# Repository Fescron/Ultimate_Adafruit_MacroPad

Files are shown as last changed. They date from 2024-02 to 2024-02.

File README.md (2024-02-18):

# Ultimate_Adafruit_MacroPad







This repository contains **necessary components** and **fabrication instructions** for my **Ultimate Adafruit Macropad**, as well as the **code and macro-definitions** I run on it. **Configuration and usage instructions** are also listed here.

I've basically added two [NeoKey 1x4 boards](https://www.adafruit.com/product/4980) next to the [Adafruit Macropad](https://www.adafruit.com/product/5128) to simplify macro-layer-switching. I've found that pressing a button to change a macro-layer on the Macropad is much faster than rotating the encoder, certainly if there are (currently) more than 25 layers defined. The encoder is repurposed to change macro-selection-layers on the NeoKey buttons. To have an additional (apart from the button color) indication of what Macropad layer can be activated using a specific NeoKey button, I've also added a [1.3" 128x64 OLED display](https://www.adafruit.com/product/938) above the NeyKey boards.

I've subsequently (heavily) modified the original [Macropad Hotkeys code](https://learn.adafruit.com/macropad-hotkeys?view=all) to work with these additional buttons and display, as wel as added functionality to use other keyboard layouts (using code from [this](https://github.com/Neradoc/Circuitpython_Keyboard_Layouts) repository) and to dim the displays and button-LEDs after some time (using code from [this](https://github.com/M-Eldin/Adafruit-MacroPad-RP2040-Sleep) repository). Since the default firmware on the Macropad doesn't support two displays I've also had to compile new CircuitPython firmware to flash to the Macropad.

Ultimate Adafruit Macropad

<br>

## 0 - Repository Structure

| Folder | Contents |
|---|---|
| [`CIRCUITPY`](CIRCUITPY/) | All files *as-is* on my Ultimate Adafruit Macropad. It contains libraries (`lib`), macros (`macros`), the main `code.py`-file, a quick reference to keycodes (`Keycodes.txt`) and a [VSCode](https://code.visualstudio.com/) workspace (`workspace.code-workspace`) to quickly open some files to I can edit them. |
| [`img`](img/) | Images displayed on this README. |
| [`pcb`](pcb/) | Two (custom) [KiCad](https://www.kicad.org/) PCBs to assemble the Ultimate Adafruit Macropad. |
| [`uf2`](uf2/) | A [CircuitPython](https://circuitpython.org/) firmware-file for the Adafruit Macropad with support for two screens. |

<br>

## 1 - Construction (Hardware)

### 1.1 - Materials

The **Ultimate Adafruit Macropad** is constructed using the materials from the tables below. Note that my version is *very fancy*, with very expensive (but amazing looking) windowed keycaps. These are certainly not required, and instead an [Adafruit MacroPad RP2040 Starter Kit](https://www.adafruit.com/product/5128) with included basic keycaps and switches can also be purchased.

Also note that the NeoKey 1x4 boards ship without switches and keycaps, they need to be purchased separately. In case the [Adafruit MacroPad RP2040 Starter Kit](https://www.adafruit.com/product/5128) is bought (instead of the [Adafruit MACROPAD RP2040 Bare Bones](https://www.adafruit.com/product/5100) board) individual switches and keycaps still need to be purchased for the NeoKey boards.

| Qty | Description | Link |
|---|---|---|
| 1 | Adafruit MACROPAD RP2040 Bare Bones | https://www.adafruit.com/product/5100 |
| 2 | Kailh Mechanical Key Switches - Tactile Brown - 10 pack | https://www.adafruit.com/product/4954 |
| 2 | NeoKey 1x4 QT I2C | https://www.adafruit.com/product/4980 |
| 20 | Black Windowed Lamp R4 Keycap for MX Compatible Switches | https://www.adafruit.com/product/5112 |
| 1 | STEMMA QT / Qwiic JST SH 4-Pin Cable - 50mm Long | https://www.adafruit.com/product/4399 |
| 1 | Monochrome 1.3" 128x64 OLED graphic display - STEMMA QT / Qwiic | https://www.adafruit.com/product/938 |
| 1 | Anodized Aluminum Machined Knob - Black - 20mm Diameter | https://www.adafruit.com/product/5527 |
| 1 | Adafruit MacroPad RP2040 Enclosure + Hardware Add-on Pack | https://www.adafruit.com/product/5103 |
| 1 | Baseboard PCB | (see [these](pcb/ultimate-adafruit-macropad-baseboard/gerber/) gerber-files) |
| 1 | Keyplate PCB | (see [these](pcb/ultimate-adafruit-macropad-keyplate/gerber/) gerber-files) |

Additionally some more generic items are necessary and/or can be useful.

| Description | Usage | Link(s) |
|---|---|---|
| Male (and female) 2.54mm/0.1" pinheaders | Mounting the NeoKey and OLED boards to the Baseboard PCB | https://www.adafruit.com/product/392 https://www.adafruit.com/product/598 |
| Black Nylon Machine Screw and Stand-off Set - M2.5 Thread | Mounting the NeoKey and OLED boards to the Baseboard PCB | https://www.adafruit.com/product/3299 |
| Black Nylon Machine Screw and Stand-off Set - M3 Thread | Mounting the Macropad to the Boaseboard PCB | https://www.adafruit.com/product/4685 |
| 2 pcs Laptop riser feet | Setting the board on an angle for easier usage | https://www.aliexpress.com/item/1005003557570061.html |
| 12x5mm 40 pcs round rubber pads | Making sure the board doesn't slide around | https://www.aliexpress.com/item/33030992785.html |
| Carrying case | Protecting the board during travel | https://www.aliexpress.com/item/1005001855670902.html |

<br>

### 1.2 - Assembly

As the last two entries in the first material-table already suggested, I've also designed two custom PCBs to facilitate a fairly easy assembly and final sturdy device. The [Baseboard PCB](pcb/ultimate-adafruit-macropad-baseboard/) is used to mount all boards to a single PCB, while also facilitating some interconnections between the components. Only a single Stemma QT / Qwiic cable (in an out-of-sight spot) is required, the rest of the connections are done by the Baseboard.

The second PCB, the [Keyplace PCB](pcb/ultimate-adafruit-macropad-keyplate/), is used to secure the eight mechanical switches to the two NeoKey boards. It basically has the same functionality as the keyplace-PCB does for the Adafruit Macropad (included in the [Adafruit MacroPad RP2040 Enclosure + Hardware Add-on Pack](https://www.adafruit.com/product/5103) or [Adafruit MacroPad RP2040 Starter Kit](https://www.adafruit.com/product/5128)).

#### The assembly-steps are the following

1. Solder male 2.54mm/0.1" pinheaders to the Baseboard (one with 01x08 pins for the OLED, two with 01x06 pins for the NeoKey boards).
2. Close solder-jumper `A0` of the left-most NeoKey 1x4 board to set its I2C address to `0x31`. The right-most NeoKey 1x4 board will keep its default address of `0x30`.
3. Solder female 01x06 2.54mm/0.1" headers to the NeoKey boards.
4. Solder a female 01x08 2.54mm/0.1" header to the OLED display. Also cut the mounting-holes on the bottom of this board so it can be mounted closer to the NeoKey boards.
5. Screw the Macropad to the Baseboard using M3 hardware.
6. Screw the NeoKey boards to the Baseboard using M2.5 hardware.
7. Connect the STEMMA QT / Qwiic cable from the Macropad to the top of the left-most NeoKey board.
8. Screw the OLED display to the Baseboard using M2.5 hardware.
9. Mount the mechanical keys to the Macropad. Make sure to not forget the keyplate in between the Macropad and the keys.
10. Mount the mechanical keys to the NeoKey boards. Make sure to not forget the (custom) keyplate in between the boards and the keys.
11. Mount the rotary encoder knob on the rotary encoder. Put the keycaps on the mechanical switches. Mount the riser feet to the bottom of the Baseboard.
12. (Optional, if the carrying case is used): Cut a foam-insert for the inside of the case to keep the Ultimate Adafruit Macropad from moving around.

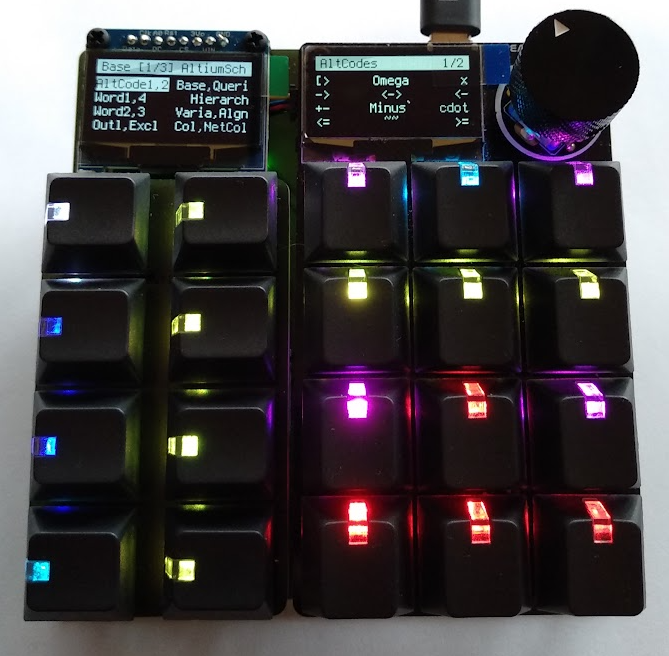
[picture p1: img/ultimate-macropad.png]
Ultimate Adafruit Macropad
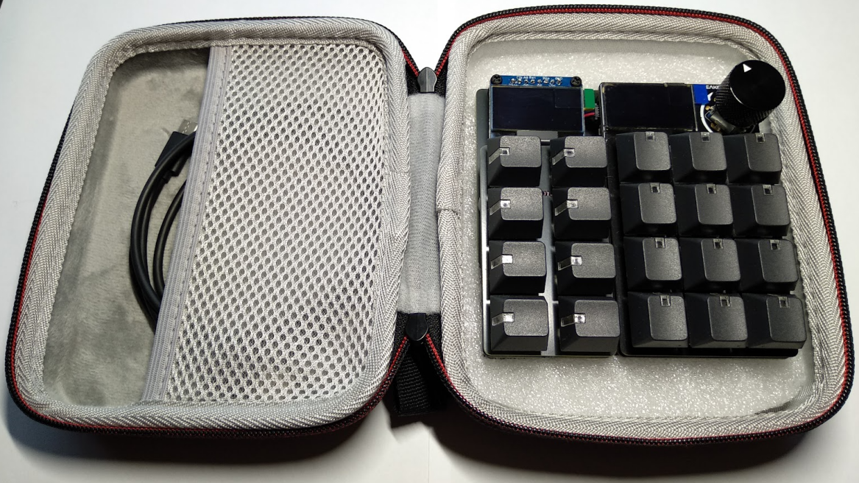
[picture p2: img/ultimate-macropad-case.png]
Ultimate Adafruit Macropad inside a case
|  |  |
|--|--|

<br>

## 2 - Firm/Software

### 2.1 - Firmware

As already mentioned, the default [CircuitPython](https://circuitpython.org/) firmware for the Adafruit Macropad doesn't support two screens. Fortunately it is possible to build `.uf2`-files yourself which do support this. The result of this is placed in the [`uf2`](uf2/) directory on this repository.

<details>

  <summary>For reference, the following (Linux/Ubuntu) steps/commands can be used to build the file yourself</summary>
  
  ```bash
  ## https://learn.adafruit.com/building-circuitpython/linux
  # Install additional software
  sudo apt install build-essential
  sudo add-apt-repository ppa:git-core/ppa
  sudo add-apt-repository ppa:pybricks/ppa
  # Download the appropriate ARM Cortex-M toolchain
  # (for CircuitpPython 8.x: 10-2020-q4-major https://developer.arm.com/downloads/-/gnu-rm)
  # Unpack it in a convenient directory
  mkdir ~/bin
  cd ~/bin
  tar xvf gcc-arm-none-eabi-10-2020-q4-major-x86_64-linux.tar.bz2
  # Add a link to the toolchain executables in PATH
  sudo nano ~/.profile
    export PATH=/home/$USER/bin/gcc-arm-none-eabi-10-2020-q4-major/bin:$PATH
  # Logout and log back in
  # Check if the link is correctly configured
  which arm-none-eabi-gcc

  ## https://learn.adafruit.com/building-circuitpython/build-circuitpython
  # Clone the repository
  git clone https://github.com/adafruit/circuitpython.git
  cd circuitpython
  # Install needed Python packages from pypi.org.
  pip3 install --upgrade -r requirements-dev.txt
  pip3 install --upgrade -r requirements-doc.txt
  # Checkout the latest stable branch (as per https://circuitpython.org/board/adafruit_macropad_rp2040/)
  git checkout 8.2.8
  # Fetch submodules (for a specific ports/... device)
  cd ports/raspberrypi
  make fetch-port-submodules
  # Build mpy-cross
  cd ../..
  make -C mpy-cross

  ## https://todbot.com/blog/2022/05/19/multiple-displays-in-circuitpython-compiling-custom-circuitpython/
  # Build for the Adafruit Macropad, with the display limit set to "2"
  cd ports/raspberrypi
  echo "#define CIRCUITPY_DISPLAY_LIMIT (2)" >> boards/adafruit_macropad_rp2040/mpconfigboard.h
  make -j12 BOARD=adafruit_macropad_rp2040
  ```

</details>

#### The firmware flashing steps are the following

1. Make sure the board is plugged-in to a computer
2. Quickly double-press the <kbd>reset</kbd> button on the Macropad to put it in the "firmware flashing" mode.
   1. If correctly activated a `RPI-RP2` drive shows up on the computer.
   2. If this doesn't work, use the following sequence to activate this mode.
      1. Hold down the encoder push-button
      2. Press the <kbd>reset</kbd> button
      3. Release the encoder push-button
3. Copy the `.uf2`-file to the `RPI-RP2` drive
4. Wait some time for the flashing to be complete

<br>

### 2.2 - Libraries (and other files)

After the firmware has been updated, the necessary libraries (and other files) need to be copied to the (Ultimate) Adafruit Macropad. One can simply copy all contents inside the [`CIRCUITPY`](CIRCUITPY/) directory of this repository to the Macropad.

<br>

### 2.3 - Software Configuration

#### 2.3.1 - Main Code

If all of the necessary files are copied to the Macropad, the customization can begin. [`CIRCUITPY/code.py`](CIRCUITPY/code.py) is the main configuration file. The macro-definitions can be found in [`CIRCUITPY/macros`](CIRCUITPY/macros). All of the files start with a number so they are sorted in a specific order. The number is also used to configure the NeoKey layers (`NEOKEY_BUTTONS`).

Inside [`CIRCUITPY/code.py`](CIRCUITPY/code.py) are a few configuration-variables to change some functionality.

- `KEYBOARD_LAYOUT`
  - `KEYBOARD_LAYOUT = 0`: Select <kbd>US QWERTY</kbd> as keyboard layout.
  - `KEYBOARD_LAYOUT = 1`: Select <kbd>Belgian AZERTY</kbd> as keyboard layout (*default*).
  - `KEYBOARD_LAYOUT = 2`: Select my <kbd>Custom Belgian AZERTY</kbd> keyboard layout where the numbers and characters on the number-row are swapped around.
- `MACRO_FOLDER`
  - `MACRO_FOLDER = '/macros'`: Select the folder where the code looks for macro-definitions.
- `NEOKEY_BUTTONS_START_LAYER`: Select the start-up NeoKey button-layer.
- `NEOKEY_BUTTONS_START_BUTTON`: Select the start-up NeoKey button.
- `NEOKEY_BUTTONS`
  - This is the NeoKey layer-definition. Layers can be changed by turning the rotary encoder on the Macropad.
  - The definition-syntax is loosely based on those of the the macro-definitions. The structure is the following (below is an example of a layer-definition).
    - A layer always needs a title-text (although it can be a zero-length string). The title is displayed on the first line of the OLED display above the NeoKey buttons.
    - The button-row definitions very closely resemble the functionality of the Macropad macro-definitions. The necessary fields are the following.
      1. A hexadecimal color-code to light-up the NeoKey button in case the page is not activated. If the layer is selected (after a button-press on the NeoKey) the key itself lights up white.
      2. A (short) text explaining the functionality present on the layer(s) which can be activated with this button. The text is also displayed in the corresponding button-location on the OLED display above the NeoKeys. The text on the screen of an activated layer also gets inverted.
      3. A list of numbers corresponding to the Macropad layers which can be activated (or cycled) after pressing a specific NeoKey button. The numbers are the same starting-numbers from the files in [`CIRCUITPY/macros`](CIRCUITPY/macros).
         - In case no macros need to be bound to a NeoKey button, make sure to still enter a (placeholder) file-number in this list. An "unused" button should have the following syntax: `(0x000000, "", [0]),`
- `TIMEOUT_S`
  - `TIMEOUT_S = 10 * 60`: Set the timeout to 10 minutes, after which the OLED displays and button-LEDs will dim. All button-functionality however still remains active.

```python
NEOKEY_BUTTONS = [
  [
    # Layer title
    "Base [1/3] AltiumSch",
    # Button definitions
    [
        # First row
        (0x004000, "AltCode1,2", [0, 1]),   # Alt-codes 1 & 2
        (0x404000, "Base,Queri", [3, 24]),  # Altium Schematic 1 & Validation Queries
        # Second row
        (0x000040, "Word1,4",    [2, 16]),  # Word 1 & 4
        (0x404000, "Hierarch",   [4]),      # Altium Schematic 2
        # Third row
        (0x000040, "Word2,3",    [20, 23]), # Word 2 & 3
        (0x404000, "Varia,Algn", [5, 22]),  # Altium Schematic 3 & Alignment
        # Fourth row
        (0x004040, "Outl,Excl",  [18, 26]), # Outlook & Excel
        (0x404000, "Col,NetCol", [15, 11])  # Altium Colors & Net-colors
    ]
  ],
]
```

<br>

#### 2.3.2 - Macropad layer-definitions

The build-up of the macro-file definitions ([`CIRCUITPY/macros`](CIRCUITPY/macros)) is unchanged compared to those of a "regular" Adafruit Macropad, and thus can perfectly be used in a "barebones" setup. Because of this the syntax won't be explicitly explained here, only some "tricks" I used when defining my macro-files.

- When there is a ``` ` ```-character at the **front** of a macro-label on the OLED display, it means a right-click mouse-action is used.
- When there is a ``` ` ```-character at the **end** of a macro-label on the OLED display, it means some sort of custom keyboard-shortcut was used. Or, in the case of the Altium *color*-pages, a non-standard color was defined.

<br>

## 3 - Usage

With the **Ultimate Adafruit Macropad** macro-definition-pages can be switched to by simply pressing one of the NeoKey buttons on the left of the Macropad, instead of rotating the encoder. The OLED display above the NeoKey buttons is used to show informating regarding these Macropad layers. The LED of the last selected (group of) page(s) lights up bright white, and the text on the OLED is inverted. The other NeoKey LEDs light up according to their defined color in `NEOKEY_BUTTONS` in the [`CIRCUITPY/code.py`](CIRCUITPY/code.py) file.

The latter file is used to do the main configuration, such as defining which Macropad layers (placed in [`CIRCUITPY/macros`](CIRCUITPY/macros)) can be activated using which NeoKey buttons. When there are multiple macro-definition-pages linked to a single NeoKey button (more than one number in the square brackets in `NEOKEY_BUTTONS`), subsequent presses on the same key rotate between all pages defined in the list. The last selected page is remembered in case another NeoKey button is pressed to select another (group of) page(s), or a whole NeoKey layer is changed using the rotary encoder. The first line on the OLED display above the NeoKey buttons also shows a title of the current layer, which is also configured in [`CIRCUITPY/code.py`](CIRCUITPY/code.py).

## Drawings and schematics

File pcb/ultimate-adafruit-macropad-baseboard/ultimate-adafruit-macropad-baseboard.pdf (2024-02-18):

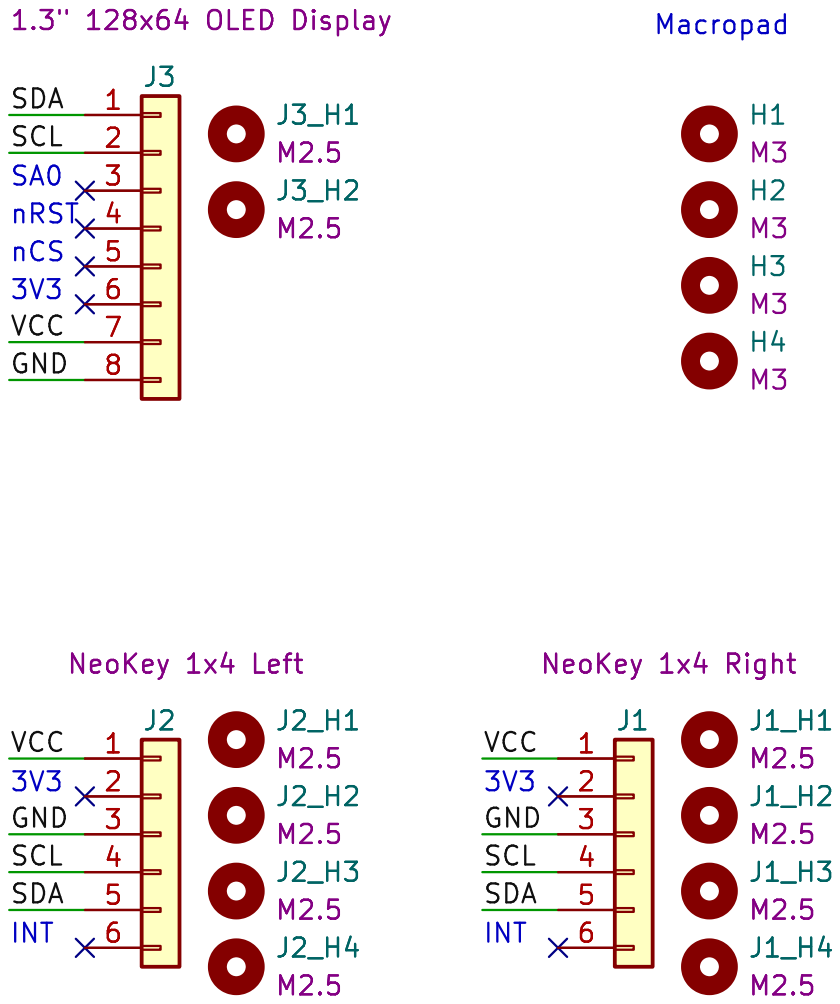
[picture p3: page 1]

Id: 1/1 Title: Ultimate Adafruit Macropad - Baseboard

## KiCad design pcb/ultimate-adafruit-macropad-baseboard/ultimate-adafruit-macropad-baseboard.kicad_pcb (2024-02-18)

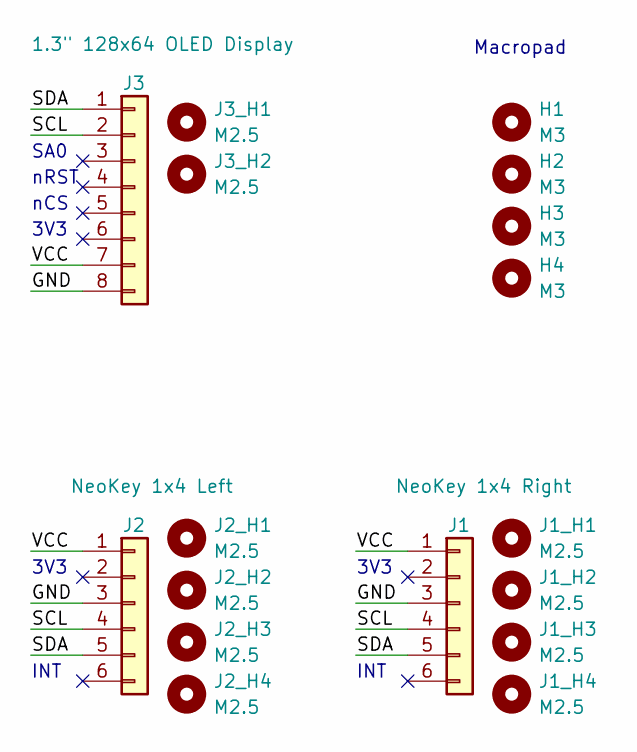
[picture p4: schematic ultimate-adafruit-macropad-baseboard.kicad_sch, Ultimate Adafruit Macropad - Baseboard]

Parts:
H1, H2, H3, H4: MountingHole; MountingHole_3.2mm_M3
J1, J2: Conn_01x06; PinSocket_1x06_P2.54mm_Vertical
J1_H1, J1_H2, J1_H3, J1_H4, J2_H1, J2_H2, J2_H3, J2_H4, J3_H1, J3_H2: MountingHole; MountingHole_2.7mm_M2.5
J3: Conn_01x08; PinSocket_1x08_P2.54mm_Vertical

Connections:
/GND: J1.3, J2.3, J3.8
/SCL: J1.4, J2.4, J3.2
/SDA: J1.5, J2.5, J3.1
/VCC: J1.1, J2.1, J3.7

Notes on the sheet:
3V3
nCS
Macropad
INT
SA0
nRST

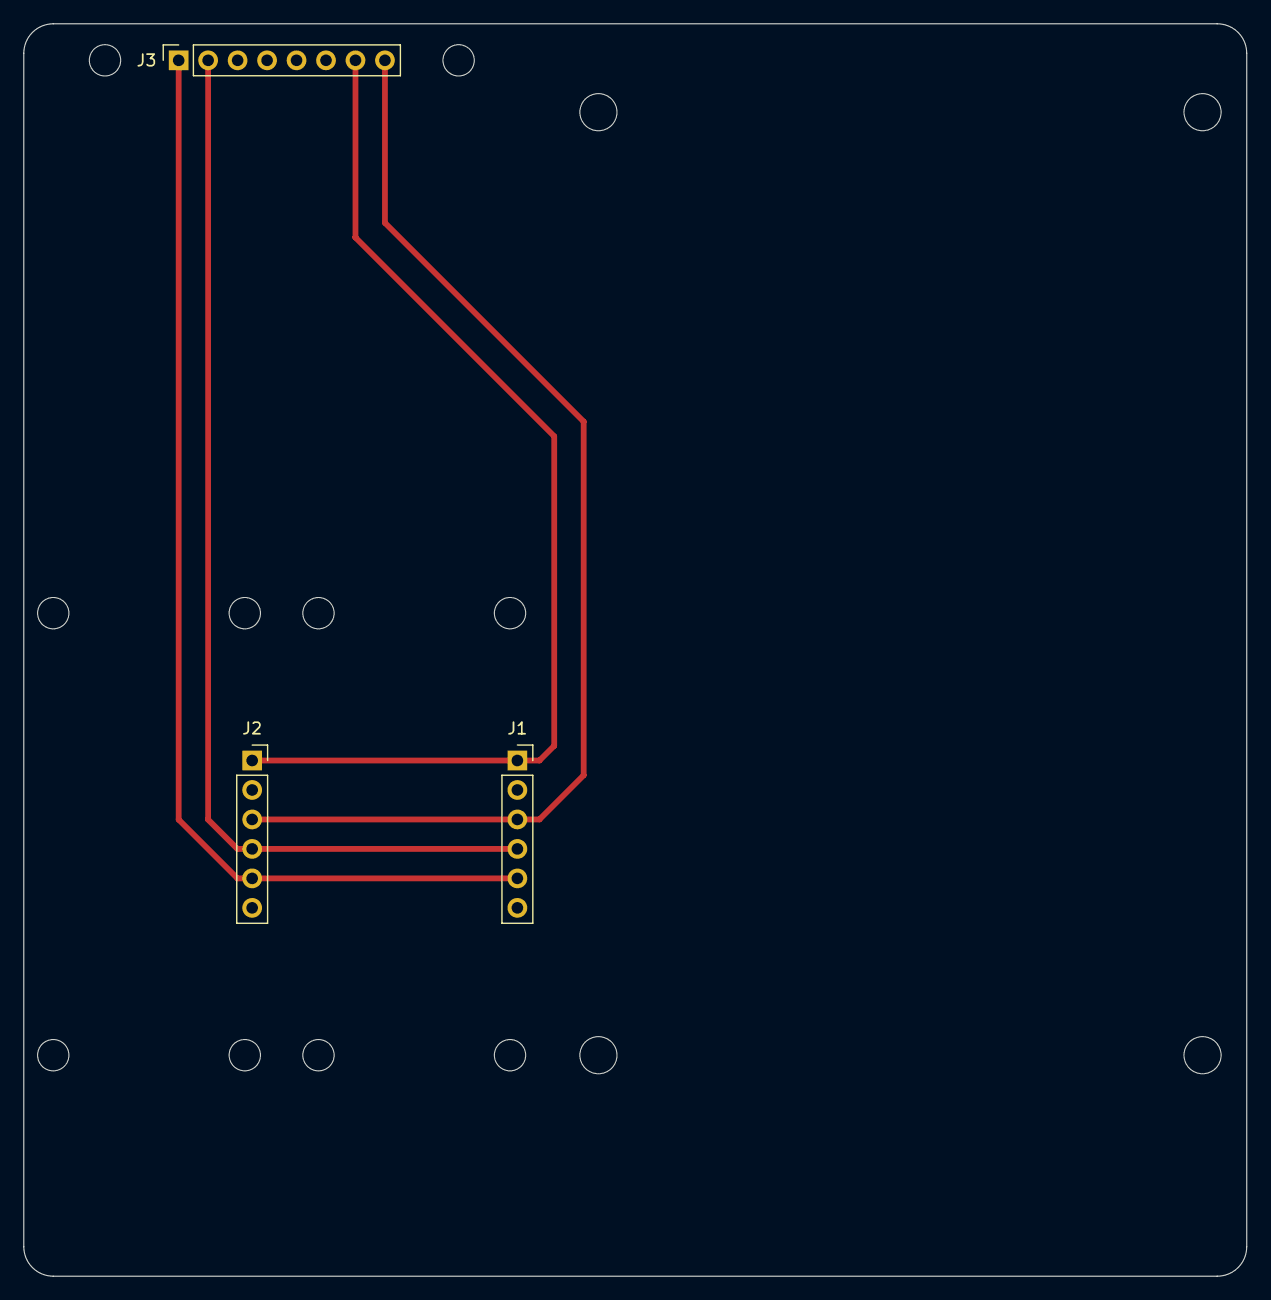
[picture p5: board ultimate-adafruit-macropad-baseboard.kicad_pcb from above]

Board: 2 copper layers, 105.4 x 107.9 mm, 17 parts (0 on the bottom side), 4 nets.

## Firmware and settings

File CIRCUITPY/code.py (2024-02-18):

"""
[08/02/2024 BRECHTVE]

A macro/hotkey program for the Adafruit MACROPAD, modified from the original Adafruit example
(see also https://learn.adafruit.com/macropad-hotkeys?view=all).

Macro setups are stored in the "/macros" folder, configurable below ("MACRO_FOLDER").
Plug the MACROPAD into the computer's USB port, use the extra NeoKey buttons
to select an application macro set (also configurable below, "NEOKEY_BUTTONS"),
and press the main MACROPAD keys to send key sequences and other USB protocols.
Use the dial to scroll through additional NeoKey layers.

The used keyboard-layout can also be configured ("KEYBOARD_LAYOUT")
(see also https://github.com/Neradoc/Circuitpython_Keyboard_Layouts).

The OLED displays and button LEDs will dim after a specified amount of time
("TIMEOUT_S"). When dimmed and pressed, the keys still send the same key-sequences
when they are not dimmed. Any press will wake up the MACROPAD lights again
(see also https://github.com/M-Eldin/Adafruit-MacroPad-RP2040-Sleep).

Connected I2C devices:
- NeoKey 1x4 (left,  0x31 = A0 jumper closed)
- NeoKey 1x4 (right, 0x30)
- 1.3" 128x64 OLED display (0x3d)

Make sure to have flashed CircuitPython firmware (.uf2) which supports two displays!
"""

# pylint: disable=import-error, unused-import, too-few-public-methods


# TODO Make sure to not light-up the Neokey1x4 LED's if the board can't get a USB-connection, ...


# 04/02/2023 BRECHTVE: Added line to select the used keyboard-layout
#  - 0 = US QWERTY
#  - 1 = Belgian AZERTY (switch to the modified layout by holding the lower-left neokey-button down on boot)
#  - 2 = Modified Belgian AZERTY (numbers and characters on number-row swapped) (switch to the regular layout by holding the lower-left neokey-button down on boot)
KEYBOARD_LAYOUT = 1


import os
import time
import displayio
import terminalio
from adafruit_display_shapes.rect import Rect
from adafruit_display_text import label
from adafruit_macropad import MacroPad

# 01/05/2022 BRECHTVE: Added lines below for the added (custom) keyboard layout support using "adafruit_macropad" v2.1.0 and later
if ((KEYBOARD_LAYOUT == 2) or (KEYBOARD_LAYOUT == 1)):
    from keyboard_layout_win_be_custom import KeyboardLayout as CustomKeyboardLayout
    from keyboard_layout_win_be import KeyboardLayout as KeyboardLayout
    from keycode_win_be import Keycode
elif (KEYBOARD_LAYOUT == 0):
    from adafruit_hid.keyboard_layout_us import KeyboardLayout
    from adafruit_hid.keycode import Keycode

# 27/04/2022 BRECHTVE: Added lines below to add Neokey1x4 functionality
import board
# import busio
from adafruit_neokey.neokey1x4 import NeoKey1x4

# 28/09/2022 BRECHTVE: Added lines below to add timeout functionality
from autoscreen import AutoOffScreen

# 09/12/2023 BRECHTVE: Added lines below to add functionality to work with an extra OLED display
import adafruit_displayio_ssd1306
import adafruit_displayio_sh1106


# CONFIGURABLES ------------------------

MACRO_FOLDER = '/macros'

# 01/05/2022 BRECHTVE: Added lines below to configure which macropad-pages can be accessed using the NeoKey1x4 buttons
NEOKEY_BUTTONS_START_LAYER  = 0
NEOKEY_BUTTONS_START_BUTTON = 6

NEOKEY_BUTTONS = [
    [
        # Layer title
        "Base [1/3] AltiumSch",
        # Button definitions
        [
            # First row
            (0x004000, "AltCode1,2", [0, 1]),   # Alt-codes 1 & 2
            (0x404000, "Base,Queri", [3, 24]),  # Altium Schematic 1 & Validation Queries
            # Second row
            (0x000040, "Word1,4",    [2, 16]),  # Word 1 & 4
            (0x404000, "Hierarch",   [4]),      # Altium Schematic 2
            # Third row
            (0x000040, "Word2,3",    [20, 23]), # Word 2 & 3
            (0x404000, "Varia,Algn", [5, 22]),  # Altium Schematic 3 & Alignment
            # Fourth row
            (0x004040, "Outl,Excl",  [18, 26]), # Outlook & Excel
            (0x404000, "Col,NetCol", [15, 11])  # Altium Colors & Net-colors
        ]
    ],
    [
        # Layer title
        "Base [2/3] AltiumLay",
        # Button definitions
        [
            # First row
            (0x004000, "AltCode1,2", [0, 1]),   # Alt-codes 1 & 2
            (0x400000, "Base,Queri", [7, 25]),  # Altium Layout 1 & Validation Queries
            # Second row
            (0x000040, "Word1,4",    [2, 16]),  # Word 1 & 4
            (0x400000, "Varia",      [8]),      # Altium Layout 2
            # Third row
            (0x000040, "Word2,3",    [20, 23]), # Word 2 & 3
            (0x000000, "",           [0]),
            # Fourth row
            (0x004040, "Outl,Excl",  [18, 26]), # Outlook & Excel
            (0x400000, "View",       [6])       # Altium Layout View
        ]
    ],
    [
        # Layer title
        "Base [3/3] Code/Zukn",
        # Button definitions
        [
            # First row
            (0x004000, "AltCode1,2", [0, 1]),   # Alt-codes 1 & 2
            (0x400040, "VSdbg,MCUX", [21, 9]),  # VScode debug & MCUXpresso IDE
            # Second row
            (0x000040, "Word1,4",    [2, 16]),  # Word 1 & 4
            (0x400040, "Clip,EmbC",  [19, 10]), # "Clipboard" & Embedded C 
            # Third row
            (0x000040, "Word2,3",    [20, 23]), # Word 2 & 3
            (0x404000, "Algn,BrdVw", [14, 17]), # CR-8000 Alignment & Board View
            # Fourth row
            (0x004040, "Outl,Excl",  [18, 26]), # Outlook & Excel
            (0x404000, "Base,Varia", [12, 13])  # CR-8000 1 & 2
        ]
    ]
    # Even more layers can be added if necessary
]

# 28/09/2022 BRECHTVE: Added line to add timeout functionality
TIMEOUT_S = 10 * 60 # Time in seconds after which the macropad should go to sleep (turn display and button LED's off, press any button to wake up)


# CLASSES AND FUNCTIONS ----------------

class App:
    """ Class representing a host-side application, for which we have a set
        of macro sequences. Project code was originally more complex and
        this was helpful, but maybe it's excessive now?"""
    def __init__(self, appdata):
        self.name = appdata['name']
        self.macros = appdata['macros']

    # 28/09/2022 BRECHTVE: Added lines below to add timeout functionality
    def set_pixels(self):
        global neokey_led_update_flag
        for i in range(12):
            if i < len(self.macros): # Key in use, set label + LED color
                macropad.pixels[i] = self.macros[i][0]
            else:  # Key not in use, no label or LED
                macropad.pixels[i] = 0
        macropad.pixels.show()
        neokey_led_update_flag = True
        updateNeokeyColors() # Turn NeoKey buttons back on

    def switch(self):
        """ Activate application settings; update OLED labels and LED
            colors. """
        group[13].text = self.name   # Application name
        for i in range(12):
            if i < len(self.macros): # Key in use, set label + LED color
                macropad.pixels[i] = self.macros[i][0]
                group[i].text = self.macros[i][1]
            else:  # Key not in use, no label or LED
                macropad.pixels[i] = 0
                group[i].text = ''
        macropad.keyboard.release_all()
        macropad.consumer_control.release()
        macropad.mouse.release_all()
        macropad.stop_tone()
        macropad.pixels.show()
        macropad.display.refresh()

# 01/05/2022 BRECHTVE: Added lines below to add NeoKey1x4 functionality
def updateNeokeyColors():
    global neokey_led_update_flag
    if neokey_led_update_flag:
        # Loop through each button
        for i in range(len(NEOKEY_BUTTONS[0][1])): # TODO Only update colors which necessitate an update?
            # Set the configured button-color if it was not pressed
            if ((i % 2) == 0): # Left NeoKey button
                if neokey_last_button_pressed[neokey_layer_index] != i:
                    neokey_l.pixels[neokey_lut[i]] = NEOKEY_BUTTONS[neokey_layer_index][1][i][0]
            else: # Right NeoKey button
                if neokey_last_button_pressed[neokey_layer_index] != i:
                    neokey_r.pixels[neokey_lut[i]] = NEOKEY_BUTTONS[neokey_layer_index][1][i][0]
        # Make the last-pressed button white
        if ((neokey_last_button_pressed[neokey_layer_index] % 2) == 0): # Left NeoKey button
            neokey_l.pixels[neokey_lut[neokey_last_button_pressed[neokey_layer_index]]] = 0xFFFFFF
        else:
            neokey_r.pixels[neokey_lut[neokey_last_button_pressed[neokey_layer_index]]] = 0xFFFFFF
        neokey_l.pixels.show()
        neokey_r.pixels.show()
        neokey_led_update_flag = False
def handleNeokeyButtonPress(button):
    global neokey_last_button_pressed, neokey_button_pressed_flag, neokey_led_update_flag # Make sure we address the correct variables
    if (neokey_last_button_pressed[neokey_layer_index] == button): # Change the "sub-page" if the same button was pressed before
        neokey_button_file_index[neokey_layer_index][button] = (neokey_button_file_index[neokey_layer_index][button] + 1) % len(NEOKEY_BUTTONS[neokey_layer_index][1][button][2])
    else: # If the same button was not pressed before, indicate that this button was pressed
        neokey_last_button_pressed[neokey_layer_index] = button
        neokey_led_update_flag = True
    neokey_button_pressed_flag = True
    autoscreen.update_active() # 28/09/2022 BRECHTVE: Added line to add timeout functionality (wakeup/stay woken up)
# 30/09/2022 BRECHTVE: Added lines below to add additional NeyKey1x4 functionality
def setAllNeoKeyColors(color):
    # Turn off Neokey1x4 LED's
    for i in range(4):
        neokey_l.pixels[i] = color
        neokey_r.pixels[i] = color
    neokey_l.pixels.show()
    neokey_r.pixels.show()

# 28/09/2022 BRECHTVE: Added lines below to add timeout functionality
def lights_on():
    macropad.display.brightness = 0.45 # Un-dim OLED display
    macropad.pixels.brightness = 1
    apps[app_index].set_pixels()
    extra_display.brightness = 1 # Un-dim extra OLED display (08/12/2023)
def lights_off():
    macropad.display.brightness = 0 # Dim OLED display
    macropad.pixels.brightness = 0
    setAllNeoKeyColors(0x000000)
    # Make the last-pressed button (dim) white
    if ((neokey_last_button_pressed[neokey_layer_index] % 2) == 0): # Left NeoKey button
        neokey_l.pixels[neokey_lut[neokey_last_button_pressed[neokey_layer_index]]] = 0x303030
        neokey_l.pixels.show()
    else:
        neokey_r.pixels[neokey_lut[neokey_last_button_pressed[neokey_layer_index]]] = 0x303030
        neokey_r.pixels.show()
    macropad.pixels.show()
    extra_display.brightness = 0 # Dim extra OLED display (08/12/2023)

# 07/12/2023 BRECHTVE: Added lines below to update the text on the extra OLED display
def updateExtraDisplay():
    refreshDisplay = False
    if extra_group[9].text != NEOKEY_BUTTONS[neokey_layer_index][0]:
        extra_group[9].text = NEOKEY_BUTTONS[neokey_layer_index][0]
        refreshDisplay = True
    for i in range(8):
        if extra_group[i].text != NEOKEY_BUTTONS[neokey_layer_index][1][i][1]:
            extra_group[i].text = NEOKEY_BUTTONS[neokey_layer_index][1][i][1]
            refreshDisplay = True
        if (i != neokey_last_button_pressed[neokey_layer_index]) and (extra_group[i].color != 0xFFFFFF):
            extra_group[i].color = 0xFFFFFF
            extra_group[i].background_color=0x000000
            refreshDisplay = True
        if i == neokey_last_button_pressed[neokey_layer_index]:
            if extra_group[i].color != 0x000000:
                extra_group[i].color = 0x000000
                extra_group[i].background_color=0xFFFFFF
                refreshDisplay = True
    if refreshDisplay:
        extra_display.refresh()

# 09/12/2023 BRECHTVE: Added lines below to add functionality to work with an extra OLED display
def setupMainDisplay():
    displayio.release_displays() 
    display_bus = displayio.FourWire(
        board.SPI(),
        command=board.OLED_DC,
        chip_select=board.OLED_CS,
        reset=board.OLED_RESET,
        baudrate=1000000,
        polarity=0, phase=0
    )
    display = adafruit_displayio_sh1106.SH1106(display_bus, width=128, height=64, colstart=2)
    macropad.display = display


# INITIALIZATION -----------------------

# 01/05/2022 BRECHTVE: Added lines below to add Neokey1x4 functionality
i2c_bus = board.I2C() # Use default I2C bus
# i2c_bus = busio.I2C(scl=board.SCL, sda=board.SDA, frequency=400000) # 09/12/2023 BRECHTVE: Increased bus-frequency BUT this gives errors when using autoreload (and doesn't seem to increase the speed much anyway?)
neokey_l = NeoKey1x4(i2c_bus, addr=0x31) # Create a NeoKey object (A0 jumper closed)
neokey_r = NeoKey1x4(i2c_bus, addr=0x30) # Create a NeoKey object
neokey_l.pixels.auto_write = False
neokey_r.pixels.auto_write = False

# 30/09/2022 BRECHTVE: Added line below to add additional NeyKey1x4 functionality
# setAllNeoKeyColors(0x000000)

# 13/07/2022 BRECHTVE: Added lines below to change to the "regular" (or modified, depending on definition at the top of the file) AZERTY keyboard-layout upon a startup-button-press
if (KEYBOARD_LAYOUT == 1):
    if neokey_l[3]:
        # Use the custom AZERTY keyboard layout
        macropad = MacroPad(
            layout_class=CustomKeyboardLayout,
            keycode_class=Keycode,
        )
        setupMainDisplay() # 09/12/2023 BRECHTVE: Added line to add functionality to work with an extra OLED display

        # Display text on the OLED to note the regular layout use
        text_lines = macropad.display_text(title="")
        text_lines[1].text = "     USING CUSTOM"
        text_lines[2].text = "     AZERTY LAYOUT"
        text_lines.show()

        # Make all LED's white to note the change
        setAllNeoKeyColors(0xFFFFFF)

        while neokey_l[3]: time.sleep(0.005) # Wait until the button is released (sleep 5ms each time)

        # Turn all LED's off to note the change
        setAllNeoKeyColors(0x000000)
    else:
        # macropad = MacroPad() # 01/05/2022 BRECHTVE: Commented line and replaced with lines below to use the added custom keyboard layout-support using "adafruit_macropad" v2.1.0 and later
        macropad = MacroPad(
            layout_class=KeyboardLayout,
            keycode_class=Keycode,
        )
        setupMainDisplay() # 09/12/2023 BRECHTVE: Added line to add functionality to work with an extra OLED display
elif (KEYBOARD_LAYOUT == 2):
    if neokey_l[3]:
        # Use the "regular" AZERTY keyboard layout
        macropad = MacroPad(
            layout_class=KeyboardLayout,
            keycode_class=Keycode,
        )
        setupMainDisplay() # 09/12/2023 BRECHTVE: Added line to add functionality to work with an extra OLED display

        # Display text on the OLED to note the regular layout use
        text_lines = macropad.display_text(title="")
        text_lines[1].text = "     USING REGULAR"
        text_lines[2].text = "     AZERTY LAYOUT"
        text_lines.show()

        # Make all LED's white to note the change
        setAllNeoKeyColors(0xFFFFFF)

        while neokey_l[3]: time.sleep(0.005) # Wait until the button is released (sleep 5ms each time)
        
        # Turn all LED's off to note the change
        setAllNeoKeyColors(0x000000)
    else:
        # macropad = MacroPad() # 01/05/2022 BRECHTVE: Commented line and replaced with lines below to use the added custom keyboard layout-support using "adafruit_macropad" v2.1.0 and later
        macropad = MacroPad(
            layout_class=CustomKeyboardLayout,
            keycode_class=Keycode,
        )
        setupMainDisplay() # 09/12/2023 BRECHTVE: Added line to add functionality to work with an extra OLED display
else:
    macropad = MacroPad(
        layout_class=KeyboardLayout,
        keycode_class=Keycode,
    )
    setupMainDisplay() # 09/12/2023 BRECHTVE: Added line to add functionality to work with an extra OLED display

# 01/05/2022 BRECHTVE: Added lines below to add Neokey1x4 functionality
neokey_layer_index = NEOKEY_BUTTONS_START_LAYER
neokey_last_button_pressed = [0]
neokey_button_pressed_flag = False
neokey_led_update_flag = False
neokey_button_file_index = [[0, 0, 0, 0, 0, 0, 0, 0]]
neokey_lut = [0, 0, 1, 1, 2, 2, 3, 3] # LUT to translate the button-numbers to left/right NeoKey-numbers
for i in range(len(NEOKEY_BUTTONS)): # Add other Neokey-layer entries if there is more than one layer
    neokey_last_button_pressed.append(0)
    neokey_button_file_index.append([0, 0, 0, 0, 0, 0, 0, 0])
neokey_last_button_pressed[neokey_layer_index] = NEOKEY_BUTTONS_START_BUTTON

macropad.display.auto_refresh = False
macropad.pixels.auto_write = False

# Set up displayio group with all the labels
group = displayio.Group()
for key_index in range(12):
    x = key_index % 3
    y = key_index // 3
    group.append(label.Label(terminalio.FONT, text='', color=0xFFFFFF,
                             anchored_position=((macropad.display.width - 1) * x / 2,
                                                macropad.display.height - 1 -
                                                (3 - y) * 12),
                             anchor_point=(x / 2, 1.0)))
group.append(Rect(0, 0, macropad.display.width, 12, fill=0xFFFFFF))
group.append(label.Label(terminalio.FONT, text='', color=0x000000,
                         anchored_position=(macropad.display.width//2, 0), # 07/12/2023 BRECHTVE: Changed "-2" to "0" to fix the vertical title-offset
                         anchor_point=(0.5, 0.0)))
macropad.display.show(group)

# Load all the macro key setups from .py files in MACRO_FOLDER
apps = []
files = os.listdir(MACRO_FOLDER)
files.sort()
for filename in files:
    if filename.endswith('.py'):
        try:
            module = __import__(MACRO_FOLDER + '/' + filename[:-3])
            apps.append(App(module.app))
        except (SyntaxError, ImportError, AttributeError, KeyError, NameError,
                IndexError, TypeError) as err:
            print("ERROR in", filename)
            import traceback
            traceback.print_exception(err, err, err.__traceback__)

if not apps:
    group[13].text = 'NO MACRO FILES FOUND'
    macropad.display.refresh()
    while True:
        pass

last_position = None
last_encoder_switch = macropad.encoder_switch_debounced.pressed
app_index = 0
# apps[app_index].switch() # 09/12/2023 BRECHTVE: Not necessary to call this here, will get refreshed by the encoder logic...

# 28/09/2022 BRECHTVE: Added lines below to add timeout functionality
autoscreen = AutoOffScreen(TIMEOUT_S) # Set up timeout (duration [s], initial duration [s])
autoscreen.poll()
autoscreen.handle_on = lights_on
autoscreen.handle_off = lights_off

# 30/09/2022 BRECHTVE: Added line below to add additional NeyKey1x4 functionality
# updateNeokeyColors() # 09/12/2023 BRECHTVE: Not necessary to call this here, will get refreshed by the encoder logic...

# 07/12/2023 BRECHTVE: Added lines below to add functionality to work with an extra OLED display
macropad.display.brightness = 0.45 # Set the brightness of the OLED display to be about the same of the extra one
extra_display_bus = displayio.I2CDisplay(i2c_bus, device_address=0x3d)
extra_display = adafruit_displayio_ssd1306.SSD1306(extra_display_bus, width=128, height=64)
extra_display.auto_refresh = False
# Set up displayio group with all the labels
extra_group = displayio.Group()
for key_index in range(8):
    x = key_index % 2
    y = key_index // 2
    extra_group.append(label.Label(terminalio.FONT, text='', color=0xFFFFFF,
                             anchored_position=((128 - 1) * x,
                                                64 - 1 -
                                                (3 - y) * 12),
                             anchor_point=(x, 1.0)))
extra_group.append(Rect(0, 0, 128, 12, fill=0xFFFFFF))
extra_group.append(label.Label(terminalio.FONT, text='', color=0x000000,
                         anchored_position=(128//2, 0),
                         anchor_point=(0.5, 0.0)))
extra_display.root_group = extra_group
updateExtraDisplay()


# MAIN LOOP ----------------------------
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

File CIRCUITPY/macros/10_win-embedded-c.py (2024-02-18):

# MACROPAD Hotkeys: Windows Embedded-C things
# BRECHTVE 21/06/2022

from adafruit_macropad import keycodes as Kc # REQUIRED if using Kc.* values

app = {                              # REQUIRED dict, must be named 'app'
    'name' : 'Embedded C       2/2', # Application name (<20 chars)
    'macros' : [                     # List of button macros...
        # COLOR    LABEL (<7 chars)    KEY SEQUENCE
        # 1st row ----------
        (0x200000, 'temp.h', [
            '/***************************************************************************//**\n',
            '@file\ttemplate.h\n',
            '@brief\tTemplate functionality.\n',
            '@date\t05/05/2022\n',
            '@version\t1.0\n',
            '@author\tBRECHTVE\n',
            '\n',
            '*****************************************************************************\n',
            '\n',
            '@section Versions\n',
            '\n',
            '  @li v1.0: Initial version.\n',
            '\n',
            Kc.BACKSPACE, -Kc.BACKSPACE, Kc.BACKSPACE, -Kc.BACKSPACE,
            '*****************************************************************************\n',
            '\n',
            '@todo\n',
            '  **Future improvements:**@n\n',
            '  - None.\n',
            '\n',
            Kc.BACKSPACE, -Kc.BACKSPACE, Kc.BACKSPACE, -Kc.BACKSPACE,
            Kc.BACKSPACE, -Kc.BACKSPACE, Kc.BACKSPACE, -Kc.BACKSPACE,
            Kc.BACKSPACE, -Kc.BACKSPACE,
            '*****************************************************************************/\n',
            '\n',
            '\n',
            Kc.DELETE, -Kc.DELETE, Kc.DELETE, -Kc.DELETE,
            Kc.DELETE, -Kc.DELETE, Kc.DELETE, -Kc.DELETE
        ]),
		(0x200000, 'temp.h', [
            '/* Include guards prevent multiple inclusions of the same header */\n',
            '#ifndef _TEMPLATE_H_\n',
            '#define _TEMPLATE_H_\n',
            '\n',
            '\n',
            '/* Includes necessary for this header file -----------------------------------*/\n',
            '//#include <stdint.h> /* (u)intXX_t */\n',
            '\n',
            '\n',
            '/* Public definitions --------------------------------------------------------*/\n',
            '// None\n',
            '\n',
            '\n',
            '/* Public prototypes ---------------------------------------------------------*/\n',
            'void template_init (void);\n',
            '\n',
            '\n',
            '#endif /* _TEMPLATE_H_ */\n'
        ]),
        (0x200020, 'cEnum', [
            'typedef enum\n',
            '{\n',
            'Thing1, Thing2, Thing3\n',
            Kc.BACKSPACE, -Kc.BACKSPACE,
            '} template_customType_t;',
            Kc.DELETE, -Kc.DELETE, Kc.DELETE, -Kc.DELETE,
            Kc.DELETE, -Kc.DELETE, Kc.DELETE, -Kc.DELETE
        ]),
        # 2nd row ----------
        (0x200000, 'temp.c', [
            '/***************************************************************************//**\n',
            '@file\ttemplate.c\n',
            '@brief\tTemplate functionality.\n',
            '@date\t05/05/2022\n',
            '@version\t1.0\n',
            '@author\tBRECHTVE\n',
            '\n',
            '*****************************************************************************\n',
            '\n',
            '@section Versions\n',
            '\n',
            '  @li v1.0: Initial version.\n',
            '\n',
            Kc.BACKSPACE, -Kc.BACKSPACE, Kc.BACKSPACE, -Kc.BACKSPACE,
            '*****************************************************************************\n',
            '\n',
            '@todo\n',
            '  **Future improvements:**@n\n',
            '  - None.\n',
            '\n',
            Kc.BACKSPACE, -Kc.BACKSPACE, Kc.BACKSPACE, -Kc.BACKSPACE,
            Kc.BACKSPACE, -Kc.BACKSPACE, Kc.BACKSPACE, -Kc.BACKSPACE,
            Kc.BACKSPACE, -Kc.BACKSPACE,
            '*****************************************************************************/\n',
            '\n',
            '\n',
            Kc.DELETE, -Kc.DELETE, Kc.DELETE, -Kc.DELETE,
            Kc.DELETE, -Kc.DELETE, Kc.DELETE, -Kc.DELETE
        ]),
		(0x200000, 'temp.c', [
            '#include "template.h" /* Include corresponding header file */\n',
            '\n',
            '//#include <stdint.h> /* (u)intXX_t */\n',
            '\n',
            '\n',
            '/* Local definitions ---------------------------------------------------------*/\n',
            '// None\n',
            '\n',
            '\n',
            '/* Local variables -----------------------------------------------------------*/\n',
            '// None\n',
            '\n',
            '\n',
            '/* Local prototypes ----------------------------------------------------------*/\n',
            '// None\n',
            '\n',
            '\n',
            '/* Public functions ----------------------------------------------------------*/\n',
            '\n',
            '/**************************************************************************//**\n',
            '@brief\tFunction to initialize the TEMPLATE peripheral.\n',
            '@details\tThis function configures the pins as well as the TEMPLATE-settings.\n',
            '@author\tBRECHTVE\n',
            Kc.BACKSPACE, -Kc.BACKSPACE,
            '****************************************************************************/\n',
            'void template_init (void)\n',
            '{\n',
            Kc.DOWN_ARROW, -Kc.DOWN_ARROW, Kc.DOWN_ARROW, -Kc.DOWN_ARROW,
            Kc.BACKSPACE, -Kc.BACKSPACE, Kc.BACKSPACE, -Kc.BACKSPACE,
            Kc.BACKSPACE, -Kc.BACKSPACE, Kc.BACKSPACE, -Kc.BACKSPACE,
            '\n',
            '\n',
            '\n',
            '/* Local functions -----------------------------------------------------------*/\n',
            '\n',
            '// None\n'
        ]),
        (0x200020, 'SwCase', [
            'switch (template)\n',
            '{\n',
            'case constant1:\n',
            '/* Statements */\n',
            'break;\n',
            Kc.BACKSPACE, -Kc.BACKSPACE,
            '\n',
            'case constant2:\n',
            '/* Statements */\n',
            'break;\n',
            Kc.BACKSPACE, -Kc.BACKSPACE,
            '\n',
            'case sameAsDefault:\n',
            'default:\n',
            '/* Statements */'
        ]),
        # 3rd row ----------
        (0x002020, 'Doxgen', [
            '/**************************************************************************//**\n',
            '@brief\tFunction to initialize the TEMPLATE peripheral.\n',
            '@details\tThis function configures the pins as well as the TEMPLATE-settings.\n',
            '@author\tBRECHTVE\n',
            Kc.BACKSPACE, -Kc.BACKSPACE,
            '****************************************************************************/',
            Kc.DELETE, -Kc.DELETE, Kc.DELETE, -Kc.DELETE,
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

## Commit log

2023-02-04 Switched to QWERTY by default
2023-02-04 Added notes about the "`" usage in labels ## Added case link and picture
2024-02-18 Reworked everything to v1.0
    [ultimate-adafruit-macropad-baseboard.kicad_pcb, ultimate-adafruit-macropad-baseboard.kicad_sch, ultimate-adafruit-macropad-keyplate.kicad_pcb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]
2024-02-18 Added OLED display to BOM

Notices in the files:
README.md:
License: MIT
